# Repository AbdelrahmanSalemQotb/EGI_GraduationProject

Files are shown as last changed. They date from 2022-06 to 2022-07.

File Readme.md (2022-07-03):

# Ventilator-by-sensing-vital-human-functions-using-IOT #

## System Overview ##
The BVM system uses two Arduino which are Arduino UNO in order to provide continuous airflow while providing user input and WiFi module to push the data over mobile application to easily observe the patient's condition.
The system has a master Arduino, which is responsible for managing the screen and user input, and a slave Arduino that actually sends commands to the servo motors. This guarantees the system's real-time safety and enables the Arduino master to function totally independently of the Arduino slave.
We will highlight the operation of each Arduino and the WiFi module separately to provide further clarification about the technical operation of this device.

The Arduino slave operates in three distinct states to enable the device's different functions: load, on, and off. While in the 'load' state, the Arduino slave will read ventilation parameters from the Arduino master through the I2C bus, generate a new pathway based on these parameters, and swap to the 'on' state.
While in the 'on' state, the device will repeat the pathway permanently.
This means that if the Arduino slave receives a command from the master to change its state to'stop', it will never stop moving the motors.
If the master Arduino does this, the device will complete its current cycle and stop moving.

The Arduino master is mainly responsible for controlling the customer LCD and sending commands to the Arduino slave. The Arduino master controls which panel is displayed and controls input from the encoder and button. Each panel displayed by the master is flexible and configured to behave differently. This makes it simple to create panels that behave differently and communicate with the Arduino slave.

Concerning the sensors part, we here have 2 sensors which are the oximeter sensor (MAX30100) and the temperature sensor (MLX90614) that measure the main 3 parameters that COVID-19 or any chest disease affects, which are *Oxygen Ratio*, *Temperature*, and *Heart Rate*. 

When the patient hands are detected in the IR sensor field, it automatically powers on the two previous sensors. And for the results, we have 2 ways to read them; first on the LCD, or over the wifi application assisted by the wifi module that we talked about previously.

If it senses a critical value from the sensors, an alarm sound starts to announce to anyone near the patient , sends an email and notification message to the patient case observer that there's a critical value  that there's a critical value that needs to be take care of. 

## Project Video ##
Project Video (https://www.youtube.com/watch?v=IrqES9ob4Ys)

## Block Diagram ##
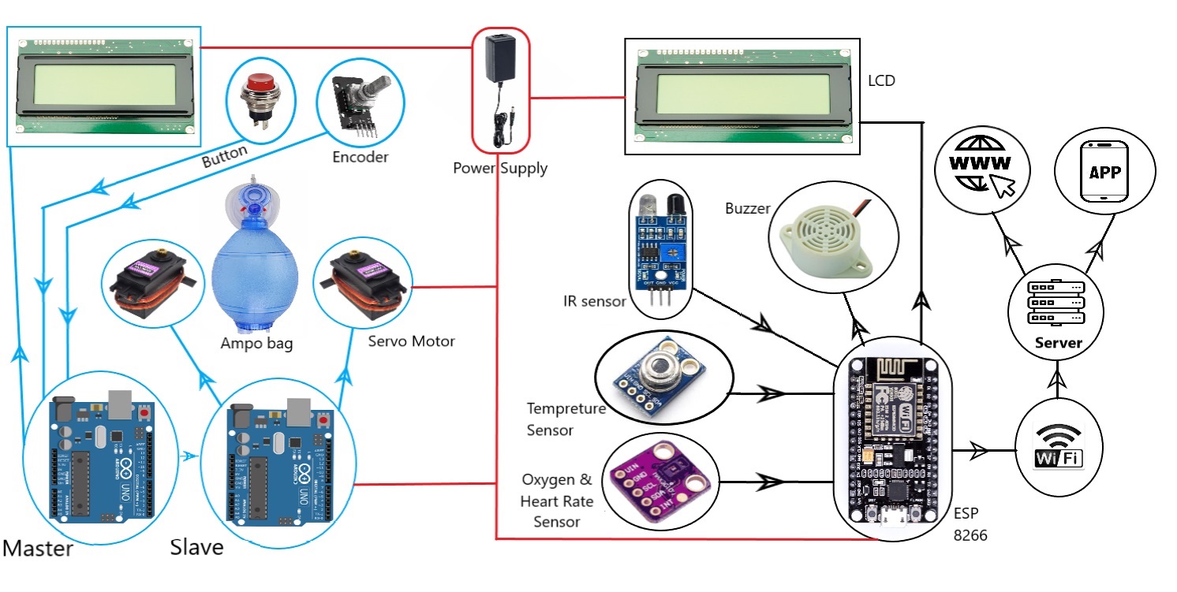
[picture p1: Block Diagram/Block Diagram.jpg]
Block Diagram


## Installation Instructions ##
1. Download the latest Arduino IDE from their website [here](https://www.arduino.cc/en/Main/Software).
2. Download the latest posted release of the device firmware [here](https://github.com/AbdelrahmanSalemQotb/Ventilator-by-sensing-vital-human-functions/releases), it should look something like "EGI_Ventilator.zip".
3. Unzip the downloaded release.
4. Add the libraries to the Arduino IDE:
    1. Copy Files to "C:\Users\\"YourUserName"\Documents\Arduino\libraries"
5. Open the slave, master and NodeMCU_V1.0 code.
    1. In the Arduino IDE, go to File->Open...
    2. Navigate to and click on the slave.ino file inside the extracted release.
    3. Repeat this process for the master.ino and NodeMCU_V1.0.ino file.
6. Flash the Arduino boards with the firmware.
    1. Plug the first Arduino board into your computer.
    2. In the Arduino IDE, go to Tools->Board and select the Arduino board you are using.
    3. Next, in the Arduino IDE, go to Tools->Port and select the port for your Arduino board.
    4. Push the arrow button to upload code on the Arduino IDE window with the slave code.
    5. Unplug the first Arduino, plug in the second, and repeat the above step for the master code.
7. Follow the [wiring diagram](https://github.com/AbdelrahmanSalemQotb/Ventilator-by-sensing-vital-human-functions/blob/Main/Wiring%20Diagram/Wring%20Diagram.png) to complete assembly.

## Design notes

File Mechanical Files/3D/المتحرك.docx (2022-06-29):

https://www.robotdigg.com/product/1223/GCr15-MGN12-Linear-Rail-and-SUS-MGN12-Linear-Block

في UGE

https://uge-one.com/mgn12c-200mm-linear-sliding-guide-rail-bearing-with-slider.html

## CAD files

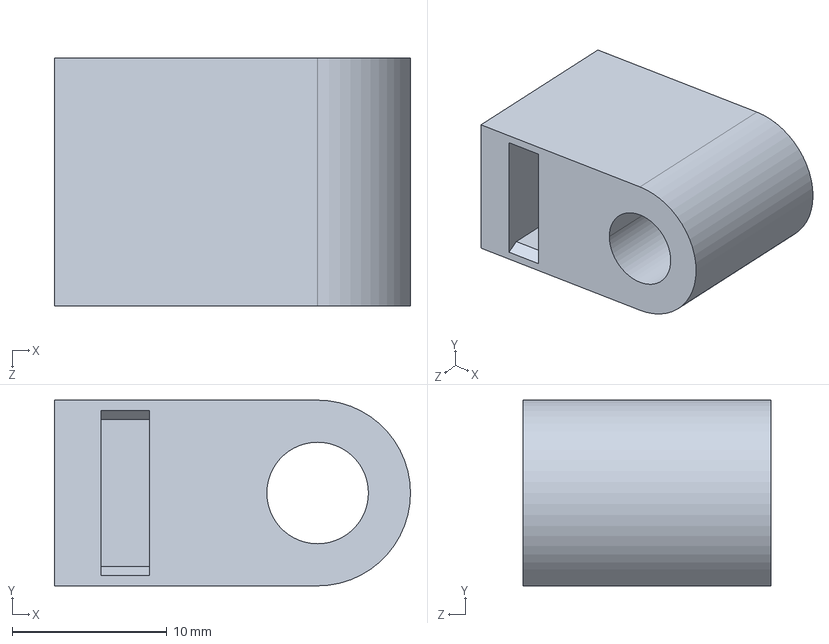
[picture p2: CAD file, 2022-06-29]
Mechanical Files/3D/STEP files/Apollo BVM - Servo Motor Mount Assembly - Servo Motor Mount - Spring Base.STEP
23.0 x 12.0 x 16.0 mm

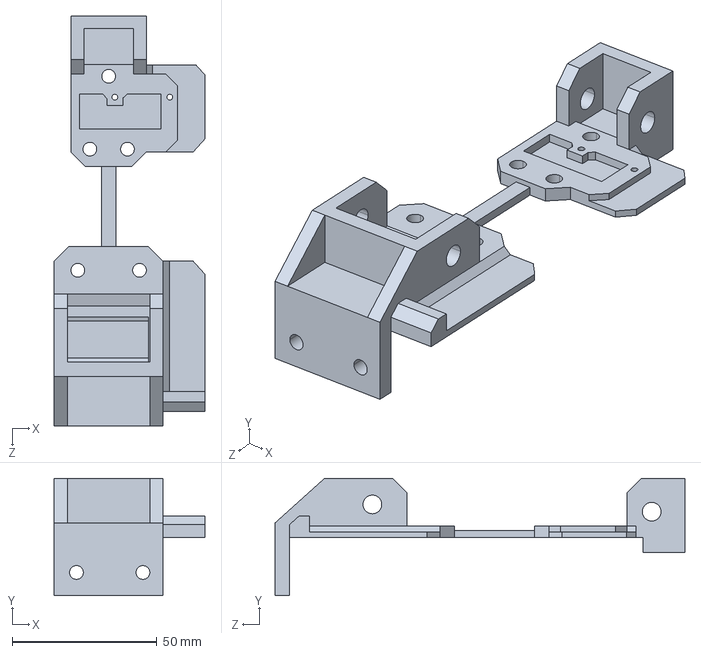
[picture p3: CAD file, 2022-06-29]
Mechanical Files/3D/STEP files/Apollo BVM - Servo Motor Mount Assembly - Base plate.STEP
52.0 x 40.5 x 141.7 mm

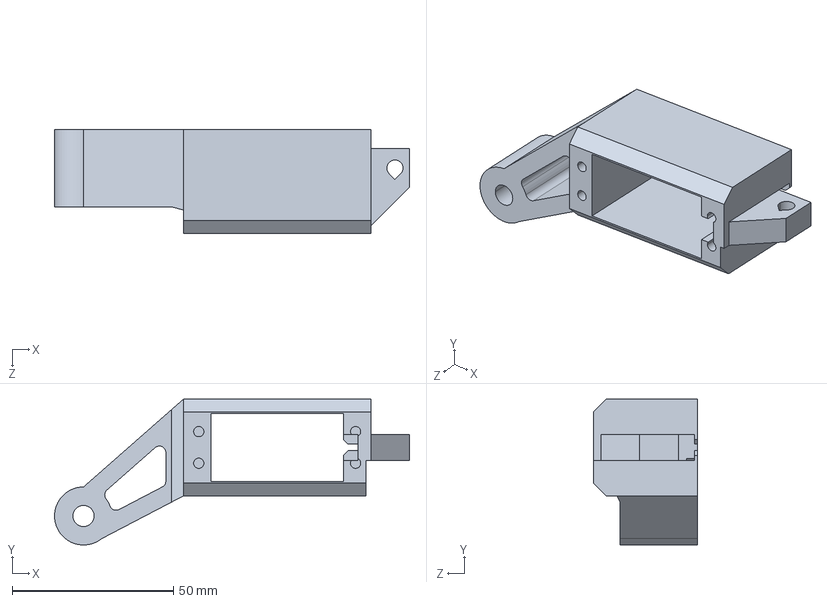
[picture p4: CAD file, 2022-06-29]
Mechanical Files/3D/STEP files/Apollo BVM - Servo Motor Mount Assembly - Servo Rotational Mount.STEP
110.0 x 45.2 x 32.3 mm

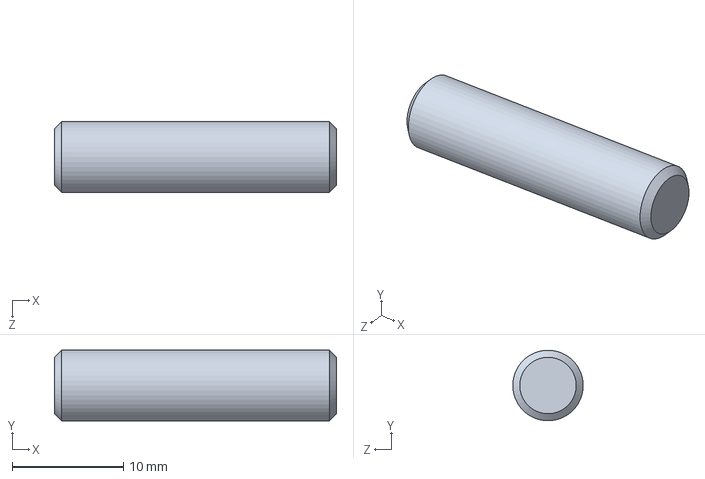
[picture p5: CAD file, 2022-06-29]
Mechanical Files/3D/2_Dowel Pin.SLDPRT
25.4 x 6.35 x 6.35 mm

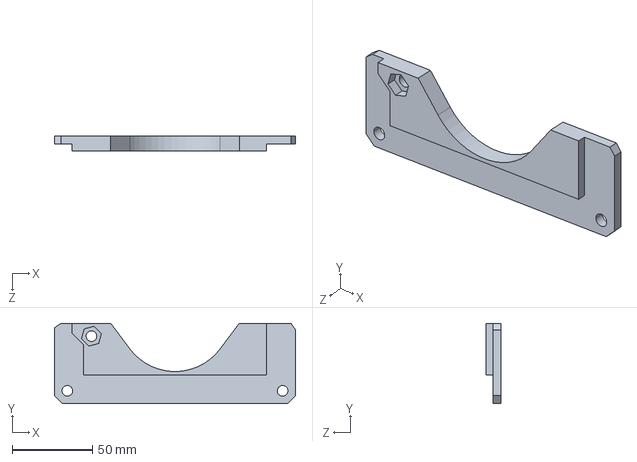
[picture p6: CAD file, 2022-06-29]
Mechanical Files/3D/STEP files/Apollo BVM - BVM Support - Bottom.STEP
150.0 x 50.0 x 9.50 mm

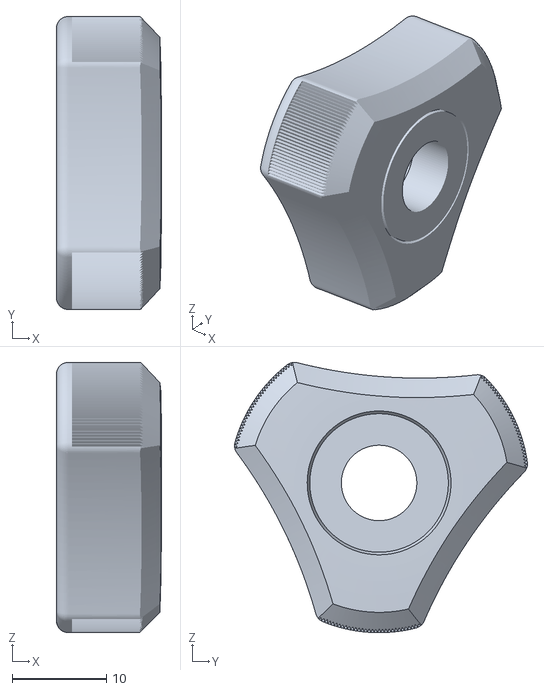
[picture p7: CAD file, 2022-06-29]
Mechanical Files/3D/STLs - 3D Print/Apollo BVM - 1_4-20 Knob.stl
11.2 x 31.1 x 28.7

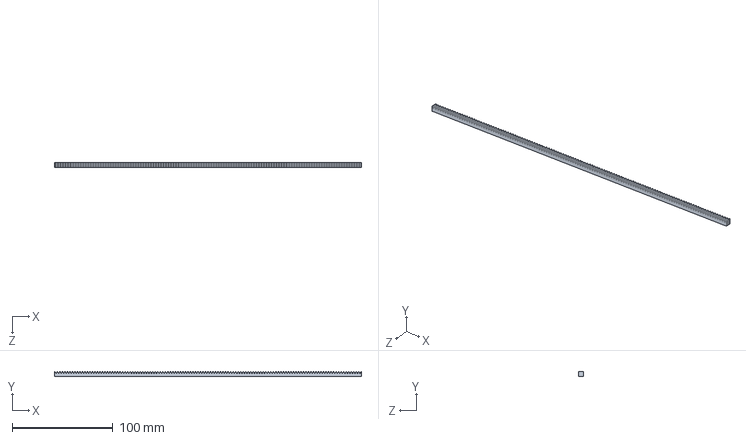
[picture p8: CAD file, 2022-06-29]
Mechanical Files/3D/2_20 Degree Pressure Angle Gear Rack (1).SLDPRT
304.8 x 4.76 x 4.76 mm

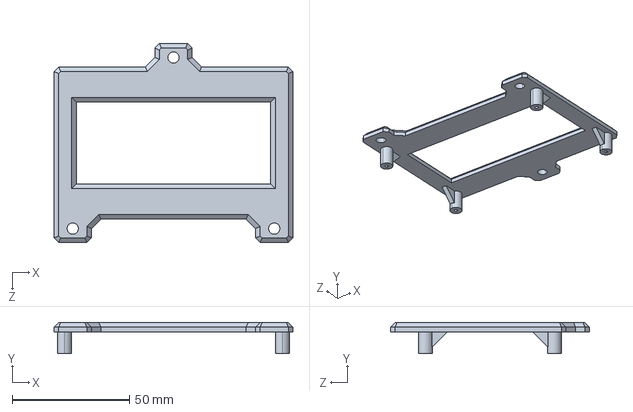
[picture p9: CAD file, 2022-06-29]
Mechanical Files/3D/STEP files/Apollo BVM - Display Mount.STEP
102.0 x 13.2 x 85.0 mm

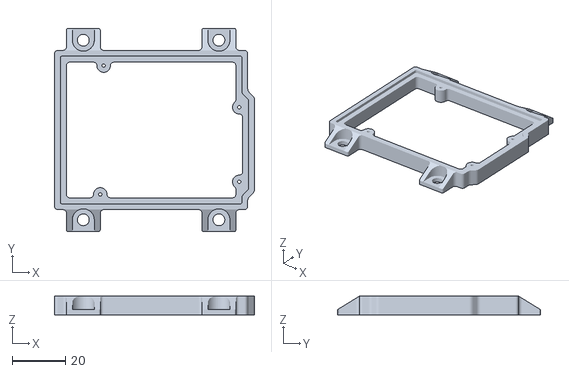
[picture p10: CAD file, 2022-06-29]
Mechanical Files/3D/STLs - 3D Print/Apollo BVM - Arduino Uno Bracket.STL
74.9 x 76.2 x 6.99

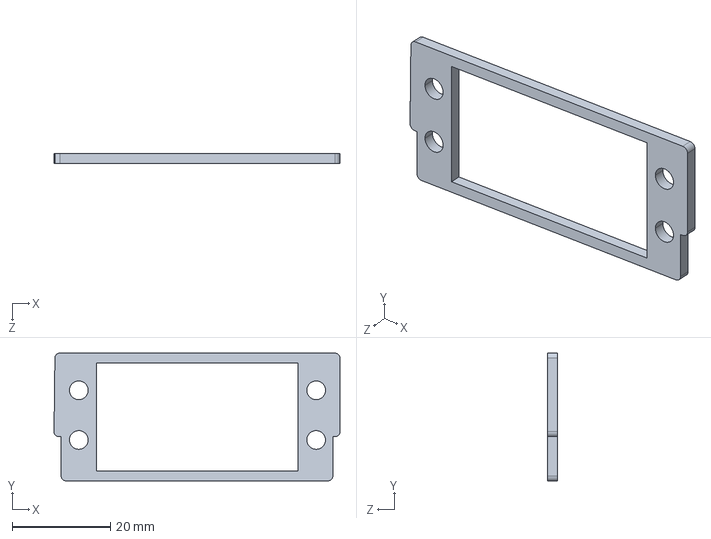
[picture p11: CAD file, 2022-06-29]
Mechanical Files/3D/STEP files/Apollo BVM - Servo shim - 2mm.STEP
58.2 x 26.0 x 2.00 mm

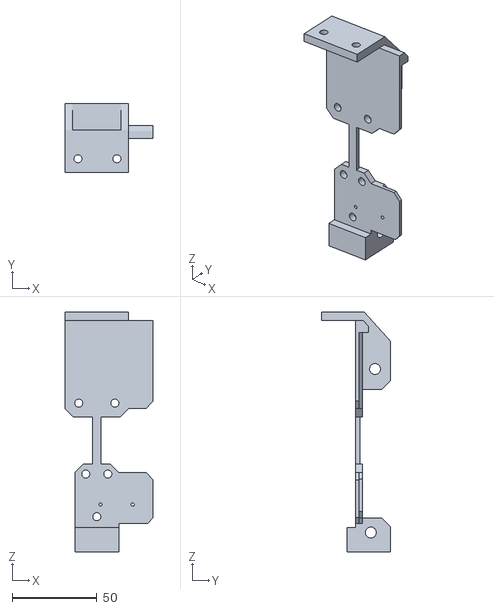
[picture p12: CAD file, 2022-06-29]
Mechanical Files/3D/STLs - 3D Print/Apollo BVM - Servo Motor Mount - Base plate.STL
52.0 x 40.5 x 141.7

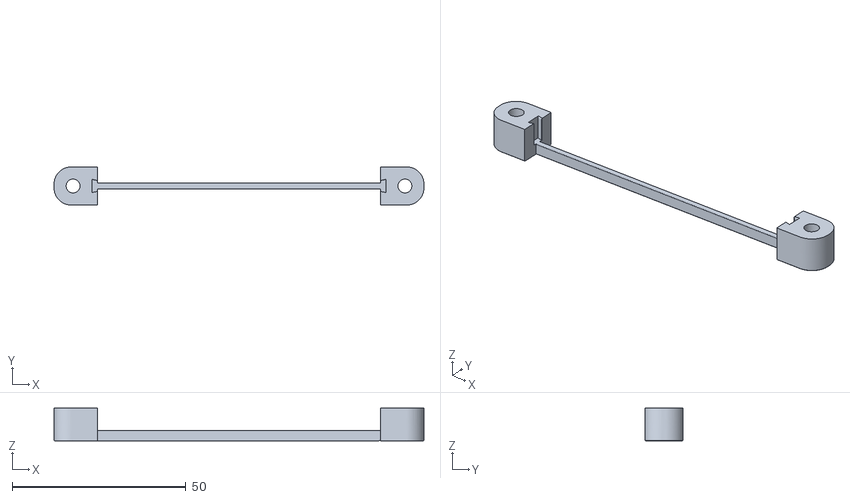
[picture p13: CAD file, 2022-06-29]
Mechanical Files/3D/STLs - 3D Print/Apollo BVM - Breadboard Brace.stl
106.6 x 11.0 x 9.40

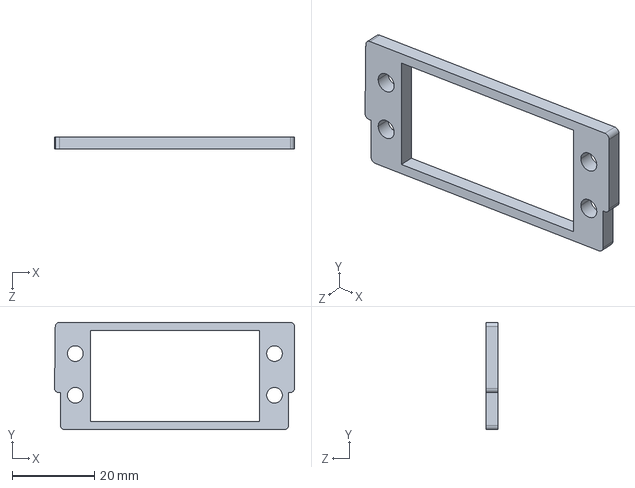
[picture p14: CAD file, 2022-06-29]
Mechanical Files/3D/STEP files/Apollo BVM - Servo shim - 3mm.STEP
58.2 x 26.0 x 3.00 mm

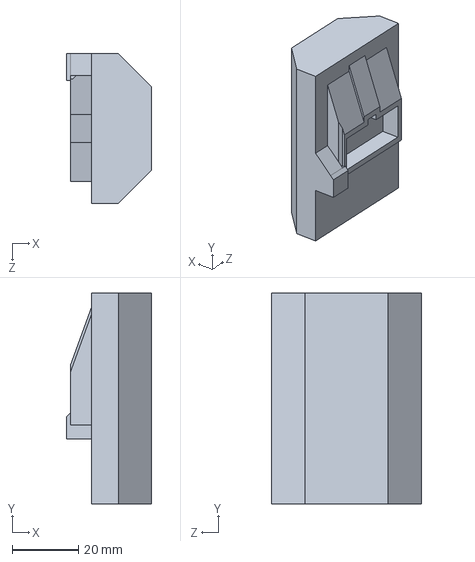
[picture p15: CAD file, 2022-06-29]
Mechanical Files/3D/STEP files/Apollo BVM - Bumper.STEP
25.6 x 63.5 x 45.0 mm

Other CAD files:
Mechanical Files/Wood/EGI_Wood.dwg
Mechanical Files/3D/STEP files/Apollo BVM - Servo shim - 1mm.STEP
Mechanical Files/3D/STEP files/Apollo BVM - BVM Support - Clamp Arm.STEP
Mechanical Files/3D/STEP files/Apollo BVM - Linear Gear Housing Base.STEP
Mechanical Files/3D/STLs - 3D Print/Apollo BVM - BVM Support - Bottom.STL
Mechanical Files/3D/STLs - 3D Print/Apollo BVM - BVM Support - Clamp Arm.STL
Mechanical Files/3D/STLs - 3D Print/Apollo BVM - Bumper.STL
Mechanical Files/3D/STLs - 3D Print/Apollo BVM - Display Mount.STL
Mechanical Files/3D/STLs - 3D Print/Apollo BVM - Linear Gear Housing Base.STL
Mechanical Files/3D/STLs - 3D Print/Apollo BVM - Servo Motor Mount Assembly - Servo Motor Mount - Spring Base.STL
Mechanical Files/3D/STLs - 3D Print/Apollo BVM - Servo Motor Mount Assembly - Servo Rotational Mount.STL
Mechanical Files/3D/STLs - 3D Print/Apollo BVM - Servo shim - 1mm.STL
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

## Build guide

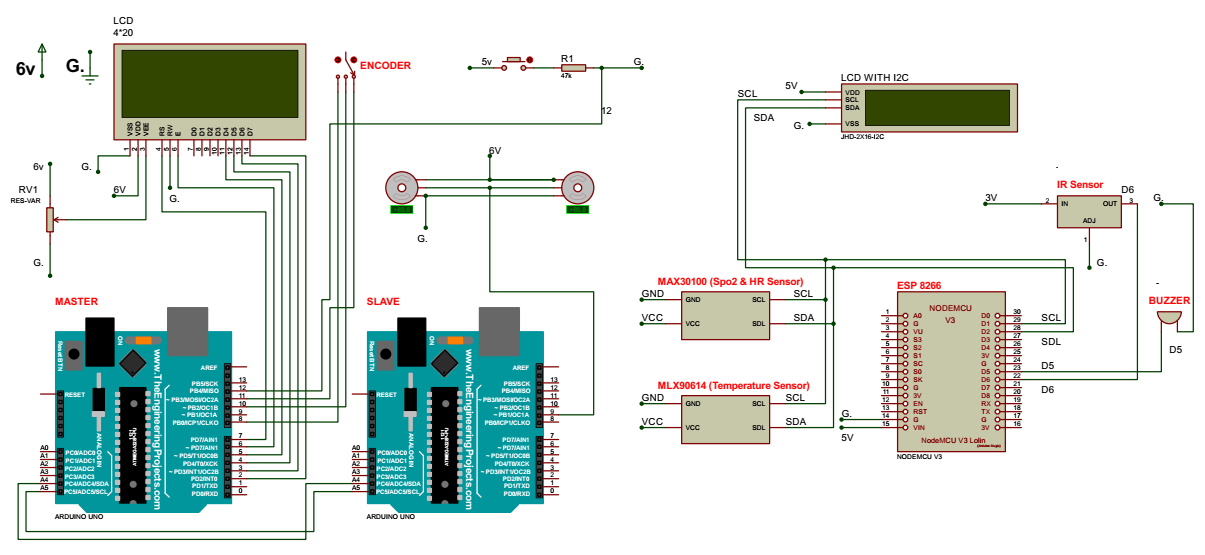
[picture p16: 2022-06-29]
Wiring Diagram/Wring Diagram.png

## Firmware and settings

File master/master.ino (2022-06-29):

#include "panel.h"
#include "Wire.h"

// Address of slave.
#define SLAVE_ADDR 8

// Pin definitions.
//#define DISPLAY_PIN 3
#define ENC_CLK_PIN 8
#define ENC_DT_PIN 10
#define ENC_BUTTON_PIN 11
#define STOP_BUTTON_PIN 12
const int rs = 7, en = 6, d4 = 5, d5 = 4, d6 = 3, d7 = 2;
// Init peripherals.
NhdDisplay display(rs, en, d4, d5, d6, d7);
Encoder enc(ENC_DT_PIN, ENC_CLK_PIN);
ButtonManager encoder_button(ENC_BUTTON_PIN, true);
ButtonManager stop_button(STOP_BUTTON_PIN, false);

// Default settings.
VentSettings vs = {'X', 500, 12, 1, 3, 0, 00, 20, 0, 0, 0, false}; 

// Default limits.
VentLimits vl;

// Calibration for TV on Ambu bag SPUR II.
int cal[9] = {950, 1062, 1155, 1238, 1320, 1393, 1465, 1538, 1610};

// String params for splash screens.
String* splash_text = new String[4];
String* warning_text = new String[4];

// Init panel pointers.
SplashPanel* splash_ptr;
SplashPanel* warning_ptr;
EditPanel* start_ptr;
EditPanel* apply_ptr;
RunningPanel* run_ptr;
PausePanel* pause_ptr;

// Init display panel pointer.
Panel* cur_panel;

void setup()
{

  // Join i2c bus.
  Wire.begin();

  // Start serial debug connection.
  Serial.begin(9600);

  // Start display.
  display.begin(20,4);
  display.clearDisplay();

  // Init slash text.
  splash_text[0] = "";
  splash_text[1] = "     E  G  I";
  splash_text[2] = "";
  splash_text[3] = "";

  //Init warning text.
  warning_text[0] = "      WARNING: ";
  warning_text[1] = "   USE ADULT SIZED";
  warning_text[2] = "   BAG VALVE MASK";
  warning_text[3] = "";

  // Init panels.
  start_ptr = new EditPanel(&display, &enc, &encoder_button, &stop_button, &vs, &vl, "Confirm & Run?", &run_ptr, 0);
  warning_ptr = new SplashPanel(&display, &enc, &encoder_button, &stop_button, &vs, warning_text, 2000, &start_ptr);
  splash_ptr = new SplashPanel(&display, &enc, &encoder_button, &stop_button, &vs, splash_text, 2000, &warning_ptr);
  apply_ptr = new EditPanel(&display, &enc, &encoder_button, &stop_button, &vs, &vl, "Apply Changes?", &run_ptr, &pause_ptr);
  run_ptr = new RunningPanel(&display, &enc, &encoder_button, &stop_button, &vs, &apply_ptr, &pause_ptr);
  pause_ptr = new PausePanel(&display, &enc, &encoder_button, &stop_button, &vs, &start_ptr, &run_ptr);

  // Delay just cause.
  delay(100);

  // Set current panel to splash.
  cur_panel = splash_ptr;
  cur_panel->start();

}

void loop()
{

  // Poll button status.
  encoder_button.poll();

  stop_button.poll();


  // Update current panel.
  Panel* new_panel = cur_panel->update();

  // If we get a new panel, start and switch to it.
  if (new_panel != 0) {
    cur_panel = new_panel;
    cur_panel->start();
  }

  // Transmit to the device if necessary.
  if (vs.send)
    transmit();
}

void transmit() {

  // Transmit to the slave device.
  Wire.beginTransmission(SLAVE_ADDR);

  // Write the mode first.
  Wire.write(vs.mode);

  // Send settings to controller unit, if we're loading.
  if (vs.mode == 'L') {
    // Calculate setpoint based on calibration.
    int setpoint = cal[(vs.tidal_volume - vl.min_tidal_volume)/vl.delta_tidal_volume];

    // Send the ventilation parameters to slave.
    Wire.write(byte(setpoint >> 8));
    Wire.write(byte(setpoint & 0x00FF));
    Wire.write(byte(vs.respiration_rate));
    Wire.write(byte(vs.inhale));
    Wire.write(byte(vs.exhale));
    Wire.write(byte(vs.hold_seconds));
    Wire.write(byte(vs.hold_decimals));
    Wire.write(byte(vs.delta_time));

    // Set the mode to on as device will start.
    vs.mode = 'O';
  }

  // Send i2c message.
  Wire.endTransmission();

  // Sent settings so disable send.
  vs.send = false;
}

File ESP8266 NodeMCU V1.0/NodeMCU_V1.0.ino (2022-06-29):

// create your own Blynk app Project then add your information below
#define BLYNK_TEMPLATE_ID ""
#define BLYNK_DEVICE_NAME ""
#define BLYNK_AUTH_TOKEN ""

//	// Uncomment for debugging
// #define Serial_Debug
// #define BLYNK_PRINT Serial
// #define BLYNK_DEBUG

#include <Wire.h>
#include <Blynk.h>
#include <ESP8266WiFi.h>
#include <BlynkSimpleEsp8266.h>
#include "MAX30100_PulseOximeter.h"
#include <Adafruit_MLX90614.h>
#include <LiquidCrystal_I2C.h>
#include <WiFiManager.h>

// Configure WIFI_Hotspot User and Pass
#define MANAGER_USER "EGI"
#define MANAGER_PASS "123456789"


#define REPORTING_PERIOD_MS 350
#define LCD_I2C_Address 0x27
#define Buzzer_Pin D5
#define IR_Pin D6

LiquidCrystal_I2C lcd(LCD_I2C_Address, 20, 4);
Adafruit_MLX90614 mlx = Adafruit_MLX90614();
PulseOximeter pox;

int BPM;
int SPO2;
byte flag = 0;
float object;
int ambiant;
uint32_t tsLastReport = 0;

byte Heart[8] = {
    0b00000,
    0b01010,
    0b11111,
    0b11111,
    0b01110,
    0b00100,
    0b00000,
    0b00000};

String ssid = ""; // Your WiFi credentials.
String pass = "";

// Callback (registered below) fired when a pulse is detected
void onBeatDetected()
{
#ifdef Serial_Debug
  Serial.println("Beat!");
#endif
  BPM = pox.getHeartRate();
  SPO2 = pox.getSpO2();
  if (SPO2 > 100 || SPO2 < 0)
  {
    SPO2 = 0;
  }
  if (digitalRead(IR_Pin))
  {
    SPO2 = 0;
    BPM = 0;
  }
}
void wifiSetup(void)
{
  WiFi.mode(WIFI_STA); // explicitly set mode, esp defaults to STA+AP

  WiFiManager wm;

  // reset settings - wipe stored credentials for testing
  // these are stored by the esp library
  //    wm.resetSettings();

  // Automatically connect using saved credentials,
  // if connection fails, it starts an access point with the specified name ( "AutoConnectAP"),
  // if empty will auto generate SSID, if password is blank it will be anonymous AP (wm.autoConnect())
  // then goes into a blocking loop awaiting configuration and will return success result

  bool res;
  lcd.setCursor(0, 0);
  lcd.print("Connect To Manager");
  lcd.setCursor(0, 1);
  lcd.print("User > ");
  lcd.print(MANAGER_USER);
  lcd.setCursor(0, 2);
  lcd.print("Pass > ");
  lcd.print(MANAGER_PASS);
  lcd.setCursor(0, 3);
  lcd.print("IP > ");
  lcd.print("192.168.4.1");

  res = wm.autoConnect(MANAGER_USER, MANAGER_PASS); // password protected ap

  if (!res)
  {
#ifdef Serial_Debug
    Serial.println("Failed to connect");
#endif
    lcd.clear();
    lcd.setCursor(0, 0);
    lcd.print("  Failed to connect");
    lcd.setCursor(0, 1);
    lcd.print("");
  }
  else
  {
    ssid = wm.getWiFiSSID();
    pass = wm.getWiFiPass();
// if you get here you have connected to the WiFi
#ifdef Serial_Debug
    Serial.println("Connected... :)");
    Serial.println(ssid);
    Serial.println(pass);
#endif
    lcd.clear();
    lcd.setCursor(0, 0);
    lcd.print("WIFI Connected");
  }
}

void LCD_Setup(void)
{
  lcd.init();

  // Make sure backlight is on
  lcd.backlight();
  lcd.createChar(0, Heart);
  // Clears the LCD screen
  lcd.clear();
}

void LCD_Report_Data(void)
{
  lcd.setCursor(0, 1);
  lcd.print("SPO2  = ");

  lcd.setCursor(0, 2);
  lcd.print("HR    = ");

  lcd.setCursor(0, 3);
  lcd.print("TEMP  = ");

  lcd.setCursor(8, 1);
  lcd.print("       ");
  lcd.setCursor(8, 1);
  lcd.print(SPO2);
  lcd.setCursor(12, 1);
  lcd.print('%');

  lcd.setCursor(8, 2);
  lcd.print("       ");
  lcd.setCursor(8, 2);
  lcd.print(BPM);
  lcd.setCursor(12, 2);
  lcd.write(0);
  lcd.print("BPM");

  lcd.setCursor(8, 3);
  lcd.print("       ");
  lcd.setCursor(8, 3);
  lcd.print((int)object);
  lcd.setCursor(12, 3);
  lcd.print((char)0xDF);
  lcd.print("C");
}

void setup()
{
#ifdef Serial_Debug
  Serial.begin(115200);
#endif
  LCD_Setup();
  wifiSetup();

  //    Blynk.begin(BLYNK_AUTH_TOKEN, ssid, pass);
  if (WiFi.status() == WL_CONNECTED)
  {
    Blynk.config(BLYNK_AUTH_TOKEN);
    if (!Blynk.connect())
    {
#ifdef Serial_Debug
      Serial.println("Server Not Connected");
#endif
      lcd.setCursor(0, 1);
      lcd.print("Server Not Connected");
      delay(1000);
    }
    else
    {
#ifdef Serial_Debug
      Serial.println("Server Connected");
#endif
      lcd.setCursor(0, 0);
      lcd.print("Server Connected");
      delay(1000);
    }
  }

  if (!mlx.begin(0x5A))
  {
#ifdef Serial_Debug
    Serial.println("MLX90614 NOT FOUND");
#endif
  }
  Wire.setClock(100000UL);
#ifdef Serial_Debug
  Serial.print("Initializing pulse oximeter..");
#endif
  // init buzzer
  pinMode(Buzzer_Pin, OUTPUT);
  pinMode(IR_Pin, INPUT);
  // Initialize the PulseOximeter instance
  if (!pox.begin())
  {
#ifdef Serial_Debug
    Serial.println("FAILED");
#endif
  }
  else
  {
#ifdef Serial_Debug
    Serial.println("SUCCESS");
#endif
  }
  pox.setOnBeatDetectedCallback(onBeatDetected);
}

void loop()
{
  if (WiFi.status() == WL_CONNECTED)
  {
    Blynk.run();
  }
  // Make sure to call update as fast as possible
  pox.update();

  if (millis() - tsLastReport > REPORTING_PERIOD_MS)
  {
    switch (flag)
    {
    case 0:
      BPM = pox.getHeartRate();
      SPO2 = pox.getSpO2();

      #ifdef Serial_Debug
        Serial.print("Heart rate:");
        Serial.print(BPM);
        Serial.print("bpm / SpO2:");
        Serial.print(SPO2);
        Serial.println("%");
      #endif
      if (SPO2 > 100 || SPO2 < 0)
      {
        SPO2 = 0;
      }

      flag = 1;
      break;

    case 1:
      if ((SPO2 > 0 && SPO2 < 90) || (BPM > 100) || ((int)object > 37))
      {
        digitalWrite(Buzzer_Pin, HIGH);
        Blynk.logEvent("critical_value",  
       ((SPO2 > 0 && SPO2 < 90)?(String("SPO2: ") + String(SPO2)):"") +
 (BPM>100?(String("  HR: ") +String(BPM)) :"" ) +
 (((int)object > 37)? (String("\nTemp: ") + String((int)object)):"") );
        #ifdef Serial_Debug
          Serial.println(" Buzzer ON");
        #endif
      }
      else
      {
        digitalWrite(Buzzer_Pin, LOW);
        #ifdef Serial_Debug
          Serial.println(" Buzzer OFF");
        #endif
      }
      flag = 2;
      break;

    case 2:
      if (!digitalRead(IR_Pin))
      {
        object = mlx.readObjectTempC();
      }
      else
      {
        object = 0;
        SPO2 = 0;
        BPM = 0;
      }

      #ifdef Serial_Debug
        Serial.print("Object = ");
        Serial.print(object);
        Serial.println();
      #endif
      flag = 3;
      break;

    case 3:
      LCD_Report_Data();
      flag = 4;
      break;

    case 4:
      if (Blynk.connected())
      {
        Blynk.virtualWrite(V3, BPM);
        Blynk.virtualWrite(V4, SPO2);
        Blynk.virtualWrite(V5, object);
        flag = 0;
      }
      else
      {
      // server not connected ( hence no report )
      flag = 0;
      #ifdef Serial_Debug
        Serial.println("Server disconnected");
      #endif
      lcd.setCursor(0, 0);
      lcd.print("Server disconnected");
      }

      break;

    default:
    break;
    }
    tsLastReport = millis();
  }
}

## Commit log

2022-04-11 add comment if i need get value on beat detection but it will not go to zero when finger move out
2022-04-20 add ir sensor .. solve the max30100 problem .. using (switch) insted of (if) {need to add server connect after disconnect}
2022-06-29 Wiring Diagram
2022-06-29 Add Mechanical Files
    [2_20 Degree Pressure Angle Gear Rack (1).SLDPRT, 2_Dowel Pin.SLDPRT, Apollo BVM - 1_4-20 Knob.stl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]
